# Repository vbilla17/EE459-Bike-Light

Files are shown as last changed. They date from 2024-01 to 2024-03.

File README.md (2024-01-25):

# EE459-Bike-Light
Repository for EE459 Capstone Project

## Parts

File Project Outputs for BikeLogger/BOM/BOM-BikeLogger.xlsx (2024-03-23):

Comment | Description | Designator | Footprint | LibRef | Quantity | Supplier Part Number 1
4.7uF | CER 4.7uF 50V X7R 1206 | C1 | C1206 | CMP-054-000019-2 | 1 | 1043596
0.1UF | CAP CER 0.1UF 50V X7R 0603 | C2, C3, C5, C6, C7, C33 | C0603 | CMP-054-000044-3 | 6 | 07X2127
1uF | CER 1UF 50V X7R 1206 | C4_B1, C4_B2, C24, C25, C29 | C1206 | CMP-054-000013-4 | 5 | 1288207
CL31B103KBCNNNC | CER 10nF 50V X7R 1206 | C8 | C1206 | CMP-054-000011-1 | 1
0.1UF | CAP CER 0.1UF 50V C0G/NP0 1206 | C9, C16, C17, C22 | C1206 | CMP-054-000012-4 | 4 | 1076805
10UF | CER 10UF 35V X7R 1206 | C10, C11, C12, C13, C14, C15, C18, C19, C20, C21, C23, C26 | C1206 | CMP-054-000014-3 | 12 | 2309034
GMC10X7R104J10NT | 0.1 µF ±5% 10V Ceramic Capacitor X7R 0603 (1608 Metric) | C27, C30, C31, C32 | GMC10X7R104J10NT-Footprint-1 | 2571-GMC10X7R104J10NTTR-ND-14 | 4
2.2uF | CAP CER 2.2UF 50V X7R 1206 | C28 | C1206 | CMP-054-000016-3 | 1 | 1276-1291-1-ND
EEEFK1E100R | CAP ALUM 10UF 20% 25V SMD | C34 | FP-FKB-MFG | CMP-05427-000055-1 | 1 | 2028597
350-1556-ND | LED ORANGE DIFFUSED 3MM T/H | D1 | 350-1556-ND-Footprint-1 | CMP-00044-1 | 1 | 1163009
151033BS03000 | Led, Blue, T-1 (3Mm), 470 Nm, 2.8 V, 30 Ma, 3.8 Cd Rohs Compliant: Yes | D2 | Type 3mm | CMP-00043-1 | 1 | 2322119
151031VS04000 | Led, Green, T-1 (3Mm), 570 Nm, 2.1 V, 30 Ma, 120 Mcd Rohs Compliant: Yes | D3 | Type 3mm | CMP-00028-6 | 1 | 2322129
HSMS-C150 | LED RED DIFFUSED 1206 2.2V 20mA | D4, D5, D6, D8 | LEDC1206 | CMP-043-000005-1 | 4 | 516-1440-1-ND
AA3528LSECKT/J3 | Red 625nm LED Indication - Discrete 1.8V 2-PLCC | D7 | New footprint 1 | CMP-00002-6 | 1
ConductiveMountingHole128Mil | 0.128" Mounting Hole w/ Conductive Pad | H1 | 128MIL_MOUNTING_HOLE | CMP-00028-00000-1 | 1
SBH11-NBPC-D03-ST-BK | SBH11-NBPC-D03-ST-BK Conn Header Vert 6POS 2.54MM | J1 | FP-SBH11-NBPC-D03-ST-BK-MFG | CMP-00595-33729071-1 | 1 | S9716-ND
1945151 | Strip Terminal Block, 8A, 1 Row(s), 1 Deck(s) | J2, J3 | 1945151-Footprint-1 | CMP-00102-1 | 2 | 1793583
282837-2 |  | J4, J6 | TE_282837-2 | 282837-2 | 2
632723100011 |  | J5 | 632723100011 | CMP-1502-03213-3 | 1 | 2984360
IHLP2020CZER4R7M11 | Inductor 4.7uH 4.5A 60mOhm | L1, L3 | IHLP2020CZER4R7M11 | CMP-030-000022-1 | 2 | 1741326
BSS84 | MOSFET P-CH 50V 130MA SOT-23 | Q1, Q2, Q3 | SOT23 | CMP-056-000000-1 | 3 | 2323155
RVQ040N05 | MOSFET N-Channel 45V 4A .065 ohm @ 5V | Q4, Q5 | TSMT6 | CMP-056-000008-2 | 2 | 5152653
RE1C002UNTCL | No Description Available | Q6, Q7, Q8 | DIO_RB558WMF_ROM | RE1C002UNTCL | 3
10k | 10K OHM 1% 1/4W 1206 | R1_B1, R1_B2, R2_B1, R2_B2, R6, R7, R13, R14, R18, R19, R26, R27, R28, R29, R30, R31 | R1206 | CMP-024-000034-3 | 16 | 2616595
ERJ-8ENF1200V | 120 OHM 1% 1/4W 1206 | R3, R24 | R1206 | CMP-024-000041-3 | 2 | 2032253
ERJ-8ENF22R0V | 22 OHM 1% 1/4W 1206 | R4 | R1206 | CMP-024-000052-3 | 1 | 2307532
51 | 51 OHM 1% 1/4W 1206 | R5, R20, R25 | R1206 | CMP-024-000074-4 | 3 | 11AC3076
ERA-8AHD300V | RES SMD 30 OHM 0.5% 1/4W 1206 | R8, R11 | R1206 | CMP-024-000012-3 | 2 | 667-ERA-8AHD300V
CRCW060330K9FKEA | 30.9k OHM 1.0% 100 mW 0603 | R9 | R0603 | CMP-024-000100-1 | 1 | 2122552
CRCW1206174KFKEA | RES Thick Film, 174kΩ, 1%, 0.25W, 100ppm/°C, 1206 | R10 | PCBComponent_1 | CMP-2003-01839-2 | 1
ERA-8AEB5232V | RES SMD 52.3K OHM 0.1% 1/4W 1206 | R12 | R1206 | CMP-024-000023-3 | 1 | 667-ERA-8AEB5232V
CRCW120636K5FKEA | RES Thick Film, 36.5kΩ, 1%, 0.25W, 100ppm/°C, 1206 | R15 | PCBComponent_1 | CMP-2003-02123-2 | 1
174k | RES Thick Film, 174kΩ, 1%, 0.25W, 100ppm/°C, 1206 | R16 | PCBComponent_1 | CMP-2003-01839-2 | 1
ERA-8AEB103V | RES SMD 10K OHM 0.1% 1/4W 1206 | R17 | R1206 | CMP-024-000007-3 | 1 | 1717751
ERJ-3EKF1001V | 1K OHM 1% 1/10W 0603 | R21, R33, R34 | R0603 | CMP-024-000028-1 | 3 | 2303145
36.5k | RES Thick Film, 36.5kΩ, 1%, 0.25W, 100ppm/°C, 1206 | R22 | PCBComponent_1 | CMP-2003-02123-2 | 1
330 | 330 OHM 1% 1/4W 1206 | R23 | R1206 | CMP-024-000058-4 | 1 | 2307628
100k | 100K OHM 1% 1/4W 1206 | R32 | R1206 | CMP-024-000035-4 | 1 | 1028504
PTS645SM43SMTR92LFS | SWITCH TACTILE SPST-NO 0.05A 12V | S1_B1, S1_B2 | FP-PTS645SM43SMTR92LFS-MFG | CMP-2000-05160-2 | 2 | 2005634
ATMEGA328PB-AU | AVR Microcontroller, 1.8 to 5.5 V, 32 KB Flash, 1 KB EEPROM, 2 KB SRAM, -40 to 85 degC, 32-Pin TQFP (32A), RoHS, Tray | U1 | ATML-32A_L | CMP-2000-07439-1 | 1
PA1616S | Ultimate GPS Module - 66 channel w/10 Hz updates - PA1616S - MTK3339 Chipset | U2 | PA1616S-Footprint-1 | CMP-00103-1 | 1
TPS56339DDCR | Buck Regulator IC Adj. 3A 4.5V-24V Input | U3, U4 | TSOT-23-6 | CMP-034-000005-2 | 2 | 296-53568-1-ND
LP2985A-18DBVJ | Single Output Low Noise LDO, 150 mA, Fixed 1.8 V Output, 1% Tolerance, 2.2 to 16 V Input, Low IQ, 5-Pin SOT-23 (DBV), -40 to 125 degC, Green (RoHS & no Sb/Br), Tape and Reel | U5 | DBV0005A_L | CMP-0758-00071-2 | 1 | 296-32155-1-ND
ICM-20948 | World’s Lowest Power 9-Axis MEMS MotionTracking(TM) Device, 1.71 to 3.6 V, -40 to 85 degC, 24-Pin QFN, RoHS, Tape and Reel | U6 | TDK-QFN-24_L | CMP-2000-07532-1 | 1 | 410-ICM-20948
CB3LV-3C-7M372800 | 1.8432MHz XO (Standard) HCMOS, TTL Oscillator 3.3V Enable/Disable 4-SMD, No Lead | Y1 | OSC_CB3LV-3C-7M372800 | CB3LV-3C-7M372800 | 1

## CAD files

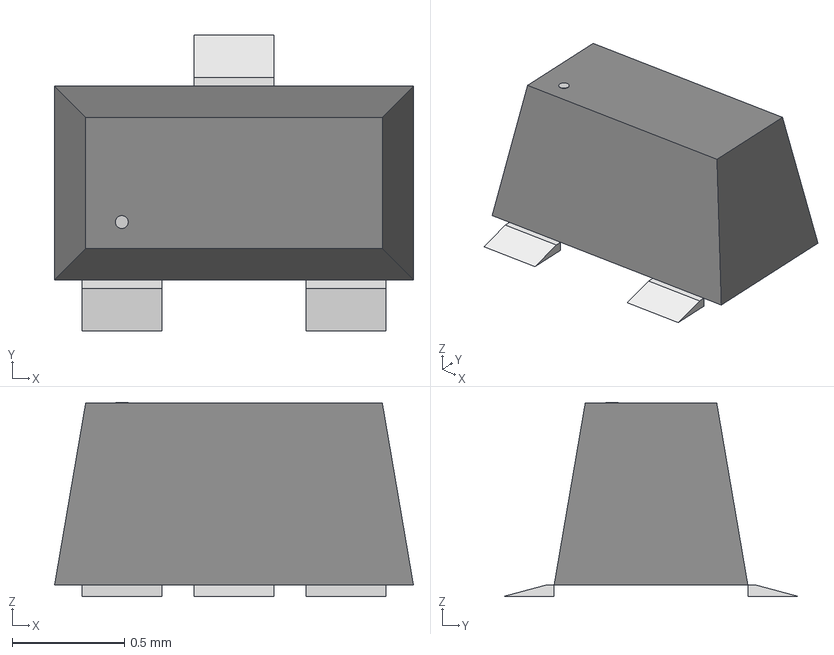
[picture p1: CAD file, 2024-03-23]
Parts/AltiumDesigner/DIO_RB558WMF_ROM.step
1.60 x 1.32 x 0.866 mm

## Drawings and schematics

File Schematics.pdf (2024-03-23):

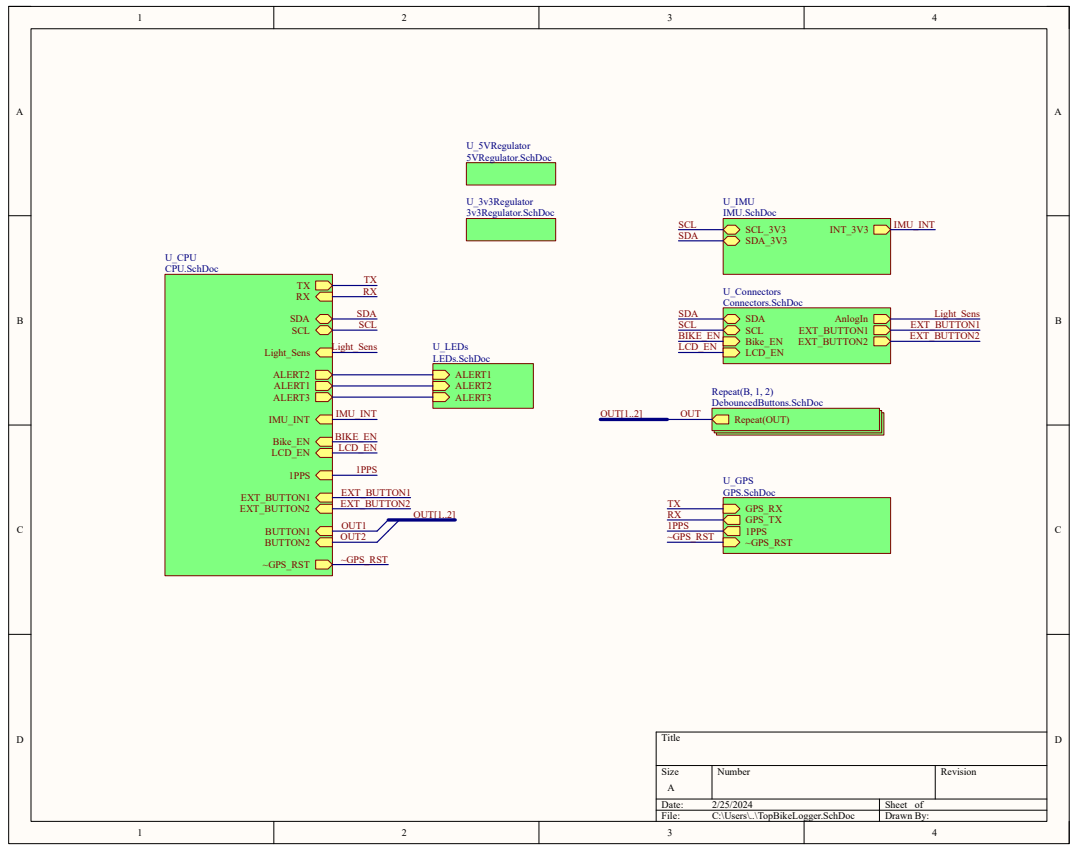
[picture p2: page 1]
Title; Size; Number; Revision; Date:; Sheet of; File:; C:\Users\..\TopBikeLogger.SchDoc; Drawn By:; Light_Sens; SDA SCL; IMU_INT; Bike_EN LCD_EN; 1PPS; EXT_BUTTON1 EXT_BUTTON2; ALERT1; ALERT2; BUTTON1 BUTTON2; ALERT3; ~GPS_RST; U_CPU CPU.SchDoc; AnlogIn EXT_BUTTON1; Bike_EN; EXT_BUTTON2; LCD_EN; U_Connectors Connectors.SchDoc; Repeat(OUT); Repeat(B, 1, 2) DebouncedButtons.SchDoc; GPS_TX; GPS_RX; U_GPS GPS.SchDoc; SCL_3V3 SDA_3V3; INT_3V3; U_IMU IMU.SchDoc; ALERT1 ALERT2 ALERT3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

## ISP Programming Interface

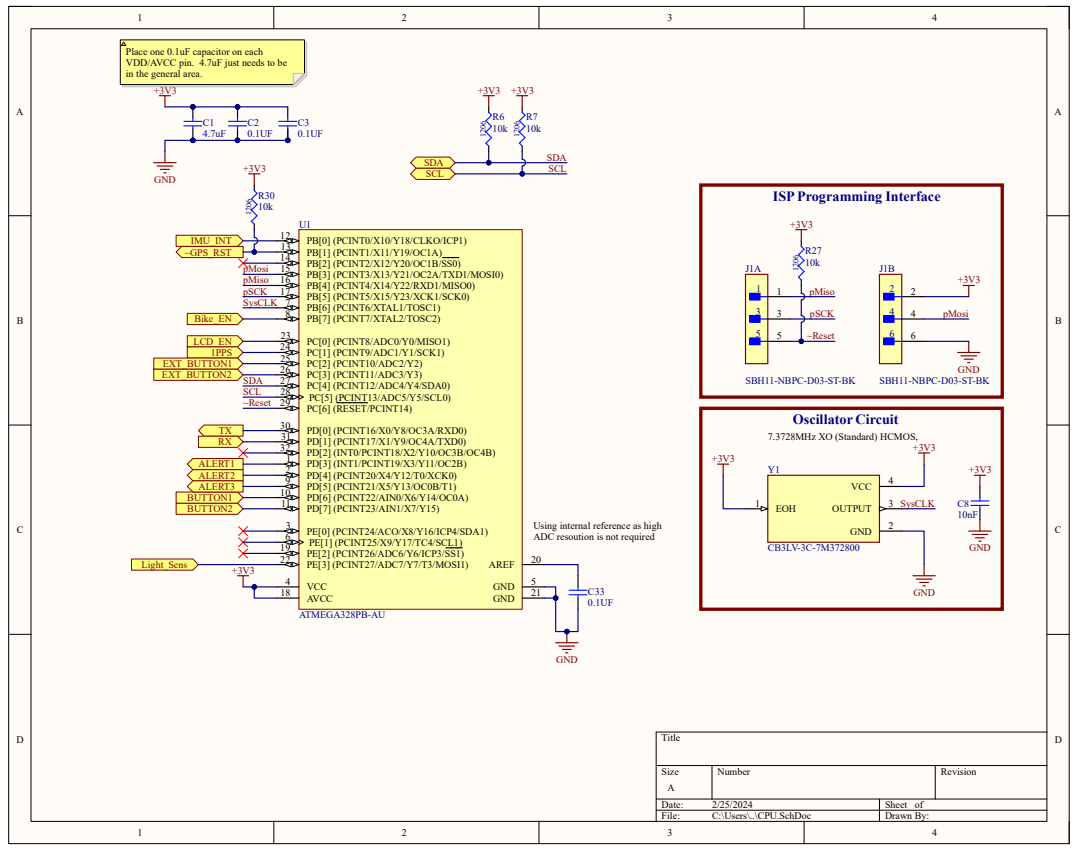
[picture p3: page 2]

Place one 0.1uF capacitor on each
VDD/AVCC pin. 4.7uF just needs to be
in the general area.

Using internal reference as high

# 3V3 REGULATOR

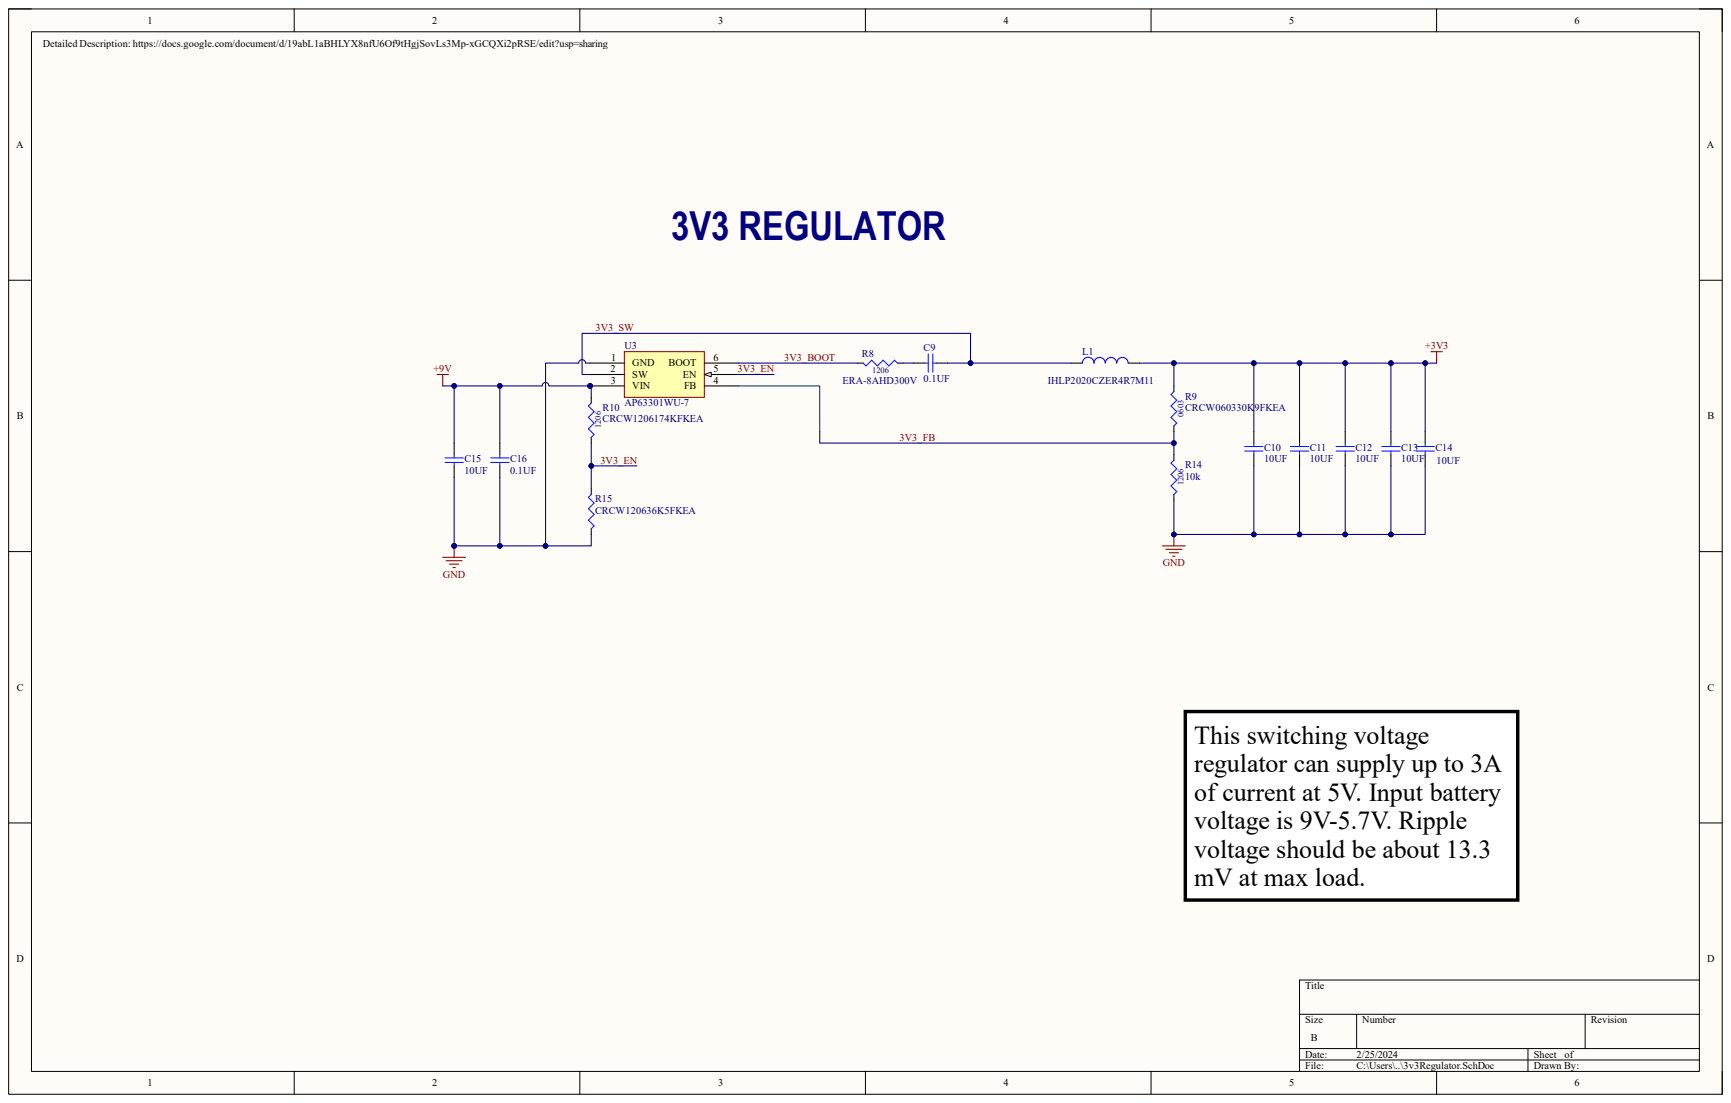
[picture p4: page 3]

This switching voltage
regulator can supply up to 3A
of current at 5V. Input battery
voltage is 9V-5.7V. Ripple
voltage should be about 13.3
mV at max load.

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
Title

Size | Number | Revision
B
Date: | 2/25/2024 | Sheet of
File: | C:\Users\..\5VRegulator.SchDoc | Drawn By:

# 5V REGULATOR

C21
10UF | 1206R13 10k

1206

R11

30 1206R12

52.3k

GND

C18
10UF

C19
10UF

C20
10UF

5V_SW

5V_FB

C17

0.1UF

C22
0.1UF

GND 1
SW 2
VIN 3
BOOT | 6
EN | 5
FB | 4

U4

AP63301WU-7

5V_BOOT

Datasheet: TI recommends an input ceramic capacitor over 10 µF for the decoupling capacitor. An additional 0.1-µF capacitor from the VIN pin to ground is recommended to provide additional high frequency filtering. The capacitor voltage rating needs to be greater than the maximum input voltage (in this case, 18V). The capacitor must also have a ripple current rating greater than the maximum input current ripple of the TPS56339, which can be calculated using the following equation.

V_OUT = 5V
V_IN_MIN = 5.7V (when battery is empty) I_OUT = 3A (max provided by this chip)

Because the decoupling capacitor is almost always conducting current to stabilize the input, the max ripple current is important to consider to ensure that the power dissipation does not cause an excessive amount of heat generated in the capacitor.

not bad!

Datasheet: A 30-Ω boot resistor and a 0.1 μF bootstrap capacitor are required between BOOT and SW. The voltage on this cap carries the gate drive voltage for the internal high-side MOSFET. TI recommends using a ceramic capacitor with X5R or better grade dielectric. The capacitor must have a 10-V or higher voltage rating. In addition, TI requires the 30 Ohm boot resistor to make the device more robust.

Datasheet: to calculate the value of the output inductor, use the following equation. K_IND is a coefficient that represents the amount of inductor ripple current relative to the maximum output current. The inductor ripple current is filtered by the output capacitor. For this part, TI
recommends K_IND no less than 30%.

Datasheet: the output voltage is set with a resistor divider from the output node to the FB pin. TI recommends using 1% tolerance or better divider resistors. Referring to the application schematic of Figure 17, we use a 10 kΩ resistor for the bottom leg and use the following equation to calculate the top leg. V_REF is nominally 0.802V.

Choosing the output capacitors affects the output ripple. To minimize output ripple, we will try to choose a lower cutoff frequency. Using the range of allowable inductor * capacitor values in the datasheet to ensure a stable control loop (Table 2 and Eqn. 14), we know the pole (cutoff) frequency must be between 8.7kHz and 16.5 kHz. We choose to target 10kHz.

Solving this equation and using 4.7uH for L1 and 10KHz for the pole frequency, we arrive at 30.9 uF of output capacitance.

We can calculate the voltage ripple on the output using the inductor ripple current and ESR of the three capacitors.

V_ripple = (inductor ripple) * ESR

Datasheet: Inductor ripple current can be found with the following equation, which is necessary to calculate the output ripple voltage.

## This switching voltage regulator can supply up to 3A of current at 5V. Input battery voltage is 9V-5.7V. Ripple voltage should be about 14.19

mV at max load.

### INPUT CAPACITOR

OUTPUT INDUCTOR | OUTPUT VOLTAGE SETTING
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

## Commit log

2024-02-27 add initial pcb files
    [282837-2.SchLib, 3v3Regulator.SchDoc, 5VRegulator.SchDoc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]
2024-03-23 init hardware commit
    [282837-2.SchLib, 36.5k.SchLib, BOM-BikeLogger.xlsx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]
